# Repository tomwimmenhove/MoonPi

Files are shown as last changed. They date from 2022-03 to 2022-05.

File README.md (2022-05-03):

A simple Linux-board with a mini PCIe slot for a 4G LTE module and a 100MBit ethernet port to use as a 4G router.

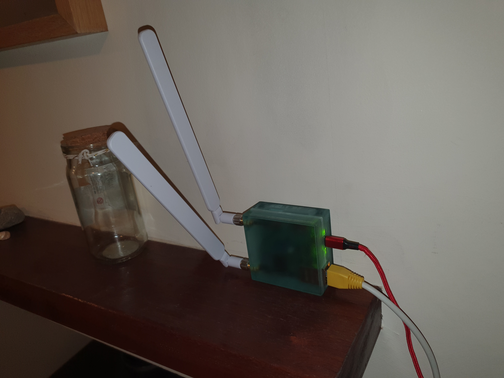
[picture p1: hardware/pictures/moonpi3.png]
MoonPi Cased


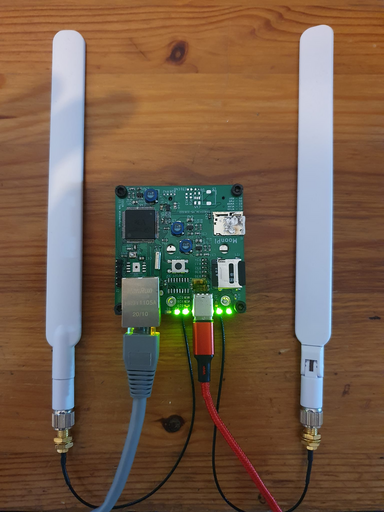
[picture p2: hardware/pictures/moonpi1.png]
MoonPi PCB front

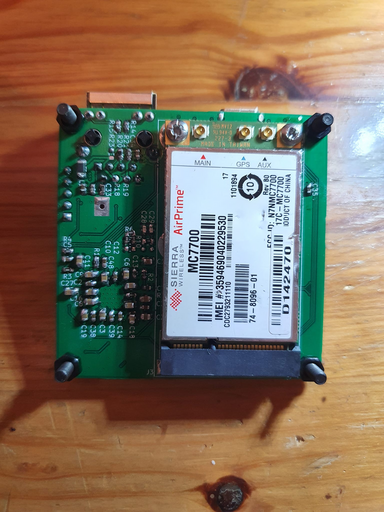
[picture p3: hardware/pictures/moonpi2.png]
MoonPi PCB bottom


Specs:
- 100MBit ethernet
- 64MB RAM
- Mini PCIe slot (for an LTE module)
- SD card slot (for firmware)
- SIM card slot
- Allwinner V3S CPU
- 115k2 baud UART console/debugging interface (Optionally over USB)

Thanks to [Dmitry Poskriyakov](https://github.com/balmerdx/AllwinnerV3S_KiCad) for creating the footprints for the used Allwinner V3S CPU.

Multiple kernel versions with working .config files can be found [here](https://github.com/tomwimmenhove/moonpi-linux/).
A U-boot .config is included in [this repository](https://github.com/tomwimmenhove/AllwinnerLTE/blob/main/software/config_notes/uboot.config) and a working version of U-Boot has been forked [here](https://github.com/tomwimmenhove/u-boot).
And finally, ~a working filesystem for the SD-card can be found [here](https://drive.google.com/drive/folders/1GH_1jrhb02dNxiufkJj9f3y94fUZBKtc)~ a working SD-card image with OpenWRT is available [here](https://github.com/tomwimmenhove/MoonPi/blob/main/software/sd_card_image/openwrt.img.gz?raw=true).

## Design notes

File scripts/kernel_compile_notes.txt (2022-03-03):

cd linux
make ARCH=arm licheepi_zero_defconfig
make ARCH=arm menuconfig #add bluethooth, etc.
make ARCH=arm CROSS_COMPILE=arm-linux-gnueabihf- -j16
make ARCH=arm CROSS_COMPILE=arm-linux-gnueabihf- -j16 INSTALL_MOD_PATH=out modules
make ARCH=arm CROSS_COMPILE=arm-linux-gnueabihf- -j16 INSTALL_MOD_PATH=out modules_install

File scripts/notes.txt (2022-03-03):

https://techship.com/faq/how-to-step-by-step-set-up-a-data-connection-over-qmi-interface-using-qmicli-and-in-kernel-driver-qmi-wwan-in-linux/
https://electronproton.com/mmcli-command-examples/
From https://forums.quectel.com/t/quectel-eg25-connection-problem/8797/5
ifconfig wwan0 down
echo Y > /sys/class/net/wwan0/qmi/raw_ip
ifconfig wwan0 up
qmicli -d /dev/cdc-wdm0 --dms-set-operating-mode=online
qmicli -p -d /dev/cdc-wdm0 --device-open-net=‘net-raw-ip|net-no-qos-header’ --wds-start-network=“autoconnect=no,apn=‘airteliot.com’,ip-type=4” --client-no-release-cid
udhcpc -i wwan0

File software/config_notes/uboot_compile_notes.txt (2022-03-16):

Repository: https://github.com/tomwimmenhove/u-boot

Branch: v3s-current
.config: uboot.config

make ARCH=arm CROSS_COMPILE=arm-linux-gnueabihf- LicheePi_Zero_defconfig
make ARCH=arm menuconfig
make ARCH=arm CROSS_COMPILE=arm-linux-gnueabihf- -j8

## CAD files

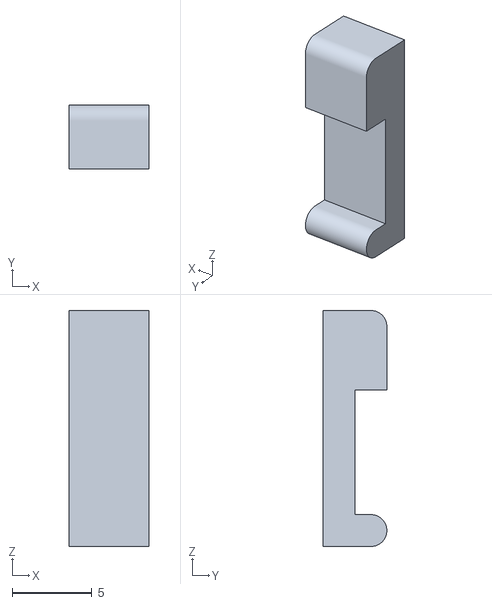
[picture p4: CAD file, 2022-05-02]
mechanical/clip.stl
5.00 x 4.00 x 14.8

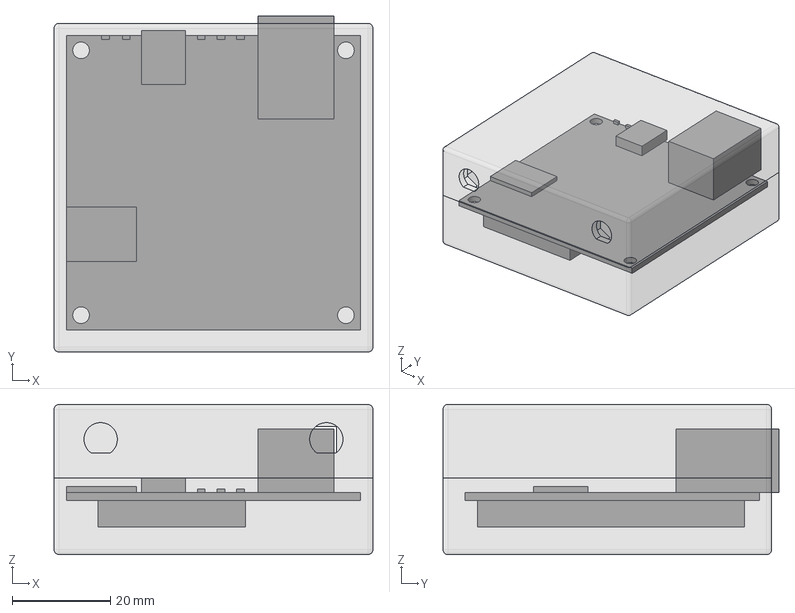
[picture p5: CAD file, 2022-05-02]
mechanical/housing.FCStd
65.0 x 68.5 x 30.6 mm
Board

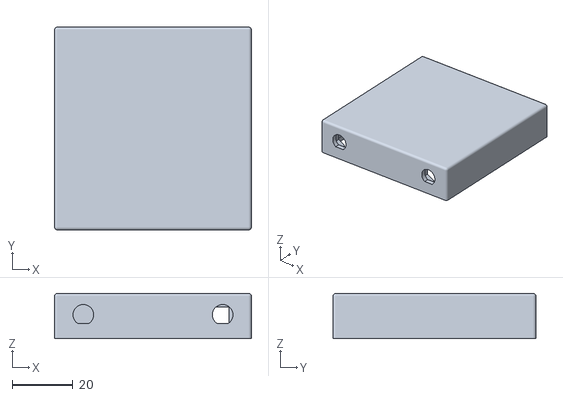
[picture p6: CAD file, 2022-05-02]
mechanical/newnewnewtop.stl
65.0 x 67.0 x 15.0

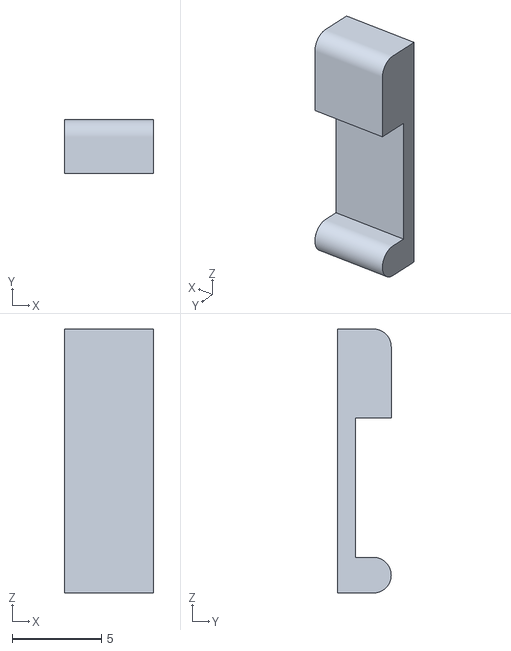
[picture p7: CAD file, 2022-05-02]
mechanical/thinclip.stl
5.00 x 3.00 x 14.8

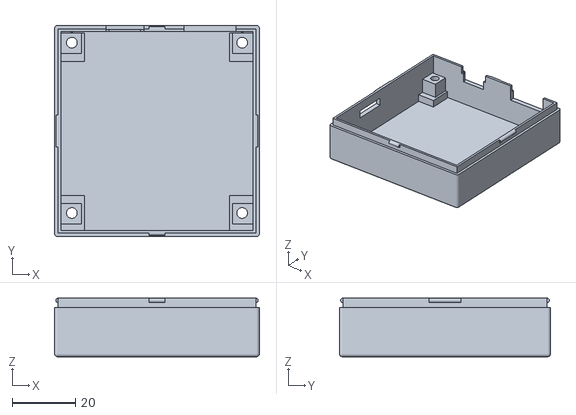
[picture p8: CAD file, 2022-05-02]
mechanical/newnewnewbottom.stl
65.0 x 67.0 x 18.6

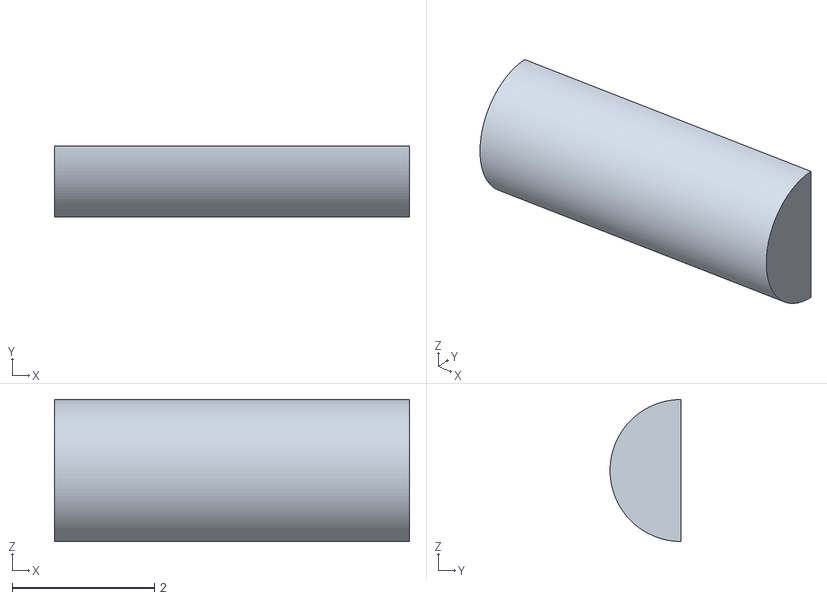
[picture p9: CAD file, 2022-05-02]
mechanical/latch.stl
5.00 x 1.00 x 2.00

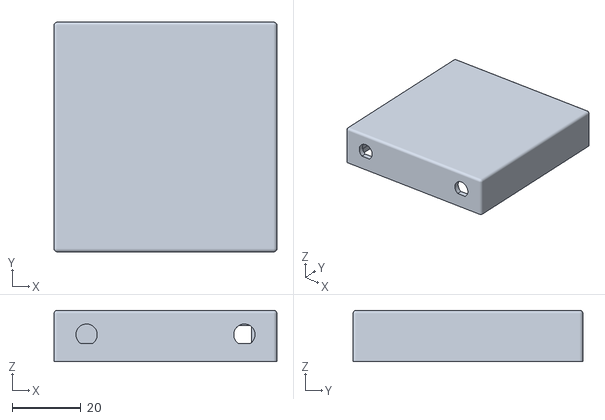
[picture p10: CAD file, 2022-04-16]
mechanical/top.stl
65.0 x 67.0 x 15.0

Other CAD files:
mechanical/newnewtop.stl
mechanical/newtop.stl
mechanical/newnewbottom.stl
mechanical/newbottom.stl
mechanical/bottom.stl

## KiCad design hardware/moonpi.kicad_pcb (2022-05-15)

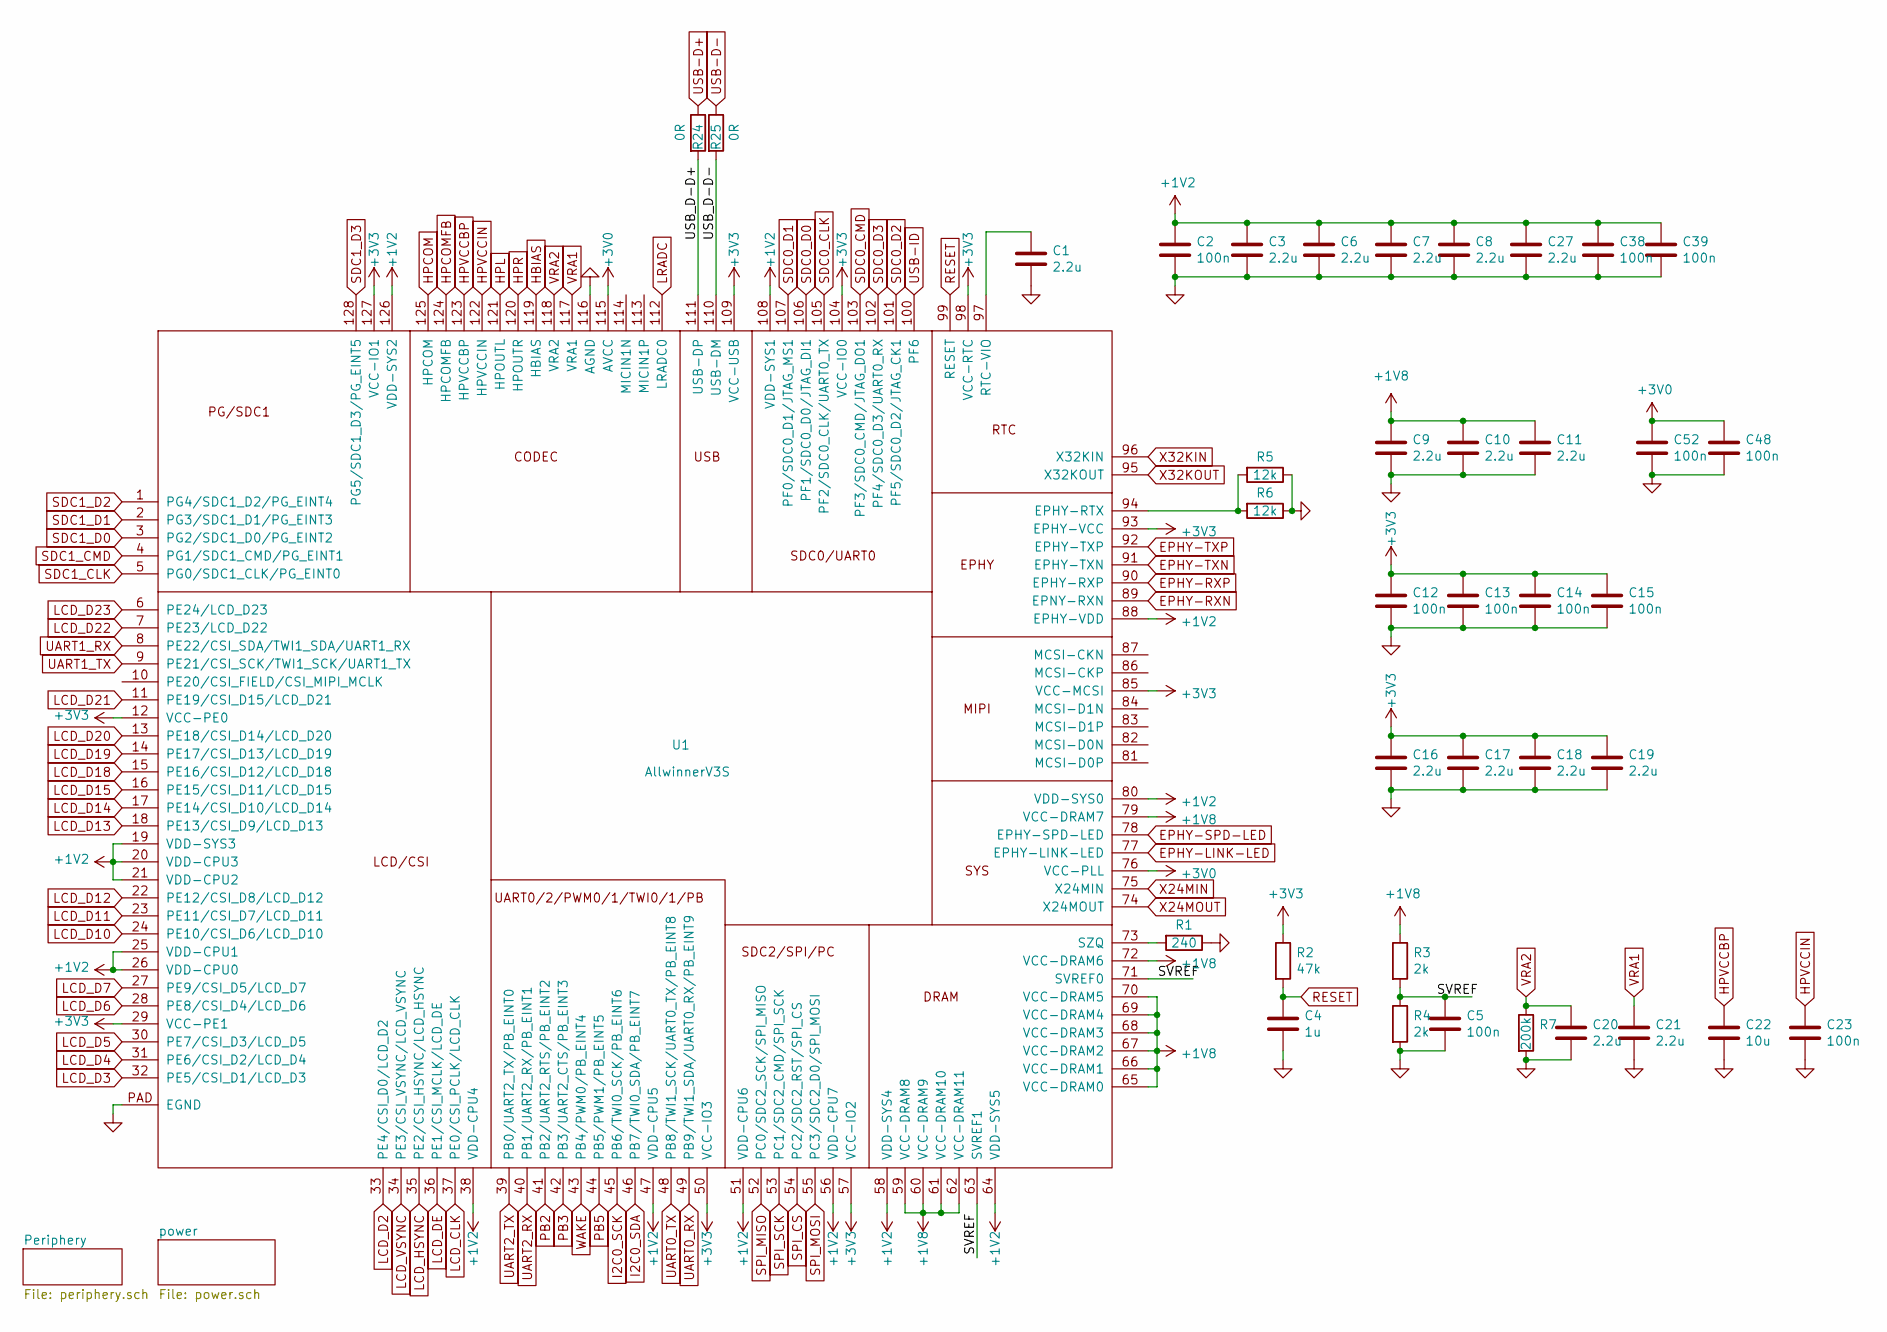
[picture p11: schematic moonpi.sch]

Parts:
C1, C3, C6, C7, C8, C9, C10, C11, C16, C17, C18, C19, C20, C21, C27: 2.2u; C_0805_2012Metric
C2, C5, C12, C13, C14, C15, C23, C38, C39, C48, C52: 100n; C_0603_1608Metric
C4: 1u; C_0603_1608Metric
C22: 10u; C_0805_2012Metric
R1: 240; R_0603_1608Metric
R2: 47k; R_0603_1608Metric
R3, R4: 2k; R_0603_1608Metric
R5, R6: 12k; R_0603_1608Metric
R7: 200k; R_0603_1608Metric
R24, R25: 0R; R_0603_1608Metric
U1: AllwinnerV3S; eLQFP-128_14x14mm_P0.4mm

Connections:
+1V2: C2.1, C3.1, C6.1, C7.1, C8.1, C27.1, C38.1, C39.1, U1.19 (VDD-SYS3), U1.20 (VDD-CPU3), U1.21 (VDD-CPU2), U1.25 (VDD-CPU1), U1.26 (VDD-CPU0), U1.38 (VDD-CPU4), U1.47 (VDD-CPU5), U1.51 (VDD-CPU6), U1.56 (VDD-CPU7), U1.58 (VDD-SYS4), U1.64 (VDD-SYS5), U1.80 (VDD-SYS0), U1.88 (EPHY-VDD), U1.108 (VDD-SYS1), U1.126 (VDD-SYS2); also elsewhere on the board
+1V8: C9.1, C10.1, C11.1, R3.1, U1.59 (VCC-DRAM8), U1.60 (VCC-DRAM9), U1.61 (VCC-DRAM10), U1.62 (VCC-DRAM11), U1.65 (VCC-DRAM0), U1.66 (VCC-DRAM1), U1.67 (VCC-DRAM2), U1.68 (VCC-DRAM3), U1.69 (VCC-DRAM4), U1.70 (VCC-DRAM5), U1.72 (VCC-DRAM6), U1.79 (VCC-DRAM7); also elsewhere on the board
+3V0: C48.1, C52.1, U1.76 (VCC-PLL), U1.115 (AVCC); also elsewhere on the board
+3V3: C12.1, C13.1, C14.1, C15.1, C16.1, C17.1, C18.1, C19.1, R2.1, U1.12 (VCC-PE0), U1.29 (VCC-PE1), U1.50 (VCC-IO3), U1.57 (VCC-IO2), U1.85 (VCC-MCSI), U1.93 (EPHY-VCC), U1.98 (VCC-RTC), U1.104 (VCC-IO0), U1.109 (VCC-USB), U1.127 (VCC-IO1); also elsewhere on the board
/SVREF: C5.1, R3.2, R4.1, U1.63 (SVREF1), U1.71 (SVREF0)
/USB_D-D+: R24.2, U1.111 (USB-DP)
/USB_D-D-: R25.2, U1.110 (USB-DM)
EPHY-LINK-LED: U1.77 (EPHY-LINK-LED); also elsewhere on the board
EPHY-RXN: U1.89 (EPNY-RXN); also elsewhere on the board
EPHY-RXP: U1.90 (EPHY-RXP); also elsewhere on the board
EPHY-SPD-LED: U1.78 (EPHY-SPD-LED); also elsewhere on the board
EPHY-TXN: U1.91 (EPHY-TXN); also elsewhere on the board
EPHY-TXP: U1.92 (EPHY-TXP); also elsewhere on the board
GND: C1.2, C2.2, C3.2, C4.2, C5.2, C6.2, C7.2, C8.2, C9.2, C10.2, C11.2, C12.2, C13.2, C14.2, C15.2, C16.2, C17.2, C18.2, C19.2, C20.2, C21.2, C22.2, C23.2, C27.2, C38.2, C39.2, C48.2, C52.2, R1.1, R4.2, R5.1, R6.1, R7.2, U1.116 (AGND), U1.PAD (EGND); also elsewhere on the board
HBIAS: U1.119 (HBIAS)
HPCOM: U1.125 (HPCOM)
HPCOMFB: U1.124 (HPCOMFB)
HPL: U1.121 (HPOUTL)
HPR: U1.120 (HPOUTR)
HPVCCBP: C22.1, U1.123 (HPVCCBP)
HPVCCIN: C23.1, U1.122 (HPVCCIN)
I2C0_SCK: U1.45 (PB6/TWI0_SCK/PB_EINT6)
I2C0_SDA: U1.46 (PB7/TWI0_SDA/PB_EINT7)
LCD_CLK: U1.37 (PE0/CSI_PCLK/LCD_CLK)
LCD_D2: U1.33 (PE4/CSI_D0/LCD_D2)
LCD_D3: U1.32 (PE5/CSI_D1/LCD_D3)
LCD_D4: U1.31 (PE6/CSI_D2/LCD_D4)
LCD_D5: U1.30 (PE7/CSI_D3/LCD_D5)
LCD_D6: U1.28 (PE8/CSI_D4/LCD_D6)
LCD_D7: U1.27 (PE9/CSI_D5/LCD_D7)
LCD_D10: U1.24 (PE10/CSI_D6/LCD_D10)
LCD_D11: U1.23 (PE11/CSI_D7/LCD_D11)
LCD_D12: U1.22 (PE12/CSI_D8/LCD_D12)
LCD_D13: U1.18 (PE13/CSI_D9/LCD_D13)
LCD_D14: U1.17 (PE14/CSI_D10/LCD_D14)
LCD_D15: U1.16 (PE15/CSI_D11/LCD_D15)
LCD_D18: U1.15 (PE16/CSI_D12/LCD_D18)
LCD_D19: U1.14 (PE17/CSI_D13/LCD_D19)
LCD_D20: U1.13 (PE18/CSI_D14/LCD_D20)
LCD_D21: U1.11 (PE19/CSI_D15/LCD_D21)
LCD_D22: U1.7 (PE23/LCD_D22)
LCD_D23: U1.6 (PE24/LCD_D23)
LCD_DE: U1.36 (PE1/CSI_MCLK/LCD_DE)
LCD_HSYNC: U1.35 (PE2/CSI_HSYNC/LCD_HSYNC)
LCD_VSYNC: U1.34 (PE3/CSI_VSYNC/LCD_VSYNC)
LRADC: U1.112 (LRADC0)
unnamed: C1.1, U1.97 (RTC-VIO)
unnamed: R1.2, U1.73 (SZQ)
unnamed: R5.2, R6.2, U1.94 (EPHY-RTX)
PB2: U1.41 (PB2/UART2_RTS/PB_EINT2)
PB3: U1.42 (PB3/UART2_CTS/PB_EINT3)
PB5: U1.44 (PB5/PWM1/PB_EINT5)
RESET: C4.1, R2.2, U1.99 (RESET); also elsewhere on the board
SDC0_CLK: U1.105 (PF2/SDC0_CLK/UART0_TX); also elsewhere on the board
SDC0_CMD: U1.103 (PF3/SDC0_CMD/JTAG_DO1); also elsewhere on the board
SDC0_D0: U1.106 (PF1/SDC0_D0/JTAG_DI1); also elsewhere on the board
SDC0_D1: U1.107 (PF0/SDC0_D1/JTAG_MS1); also elsewhere on the board
SDC0_D2: U1.101 (PF5/SDC0_D2/JTAG_CK1); also elsewhere on the board
SDC0_D3: U1.102 (PF4/SDC0_D3/UART0_RX); also elsewhere on the board
SDC1_CLK: U1.5 (PG0/SDC1_CLK/PG_EINT0); also elsewhere on the board
SDC1_CMD: U1.4 (PG1/SDC1_CMD/PG_EINT1)
SDC1_D0: U1.3 (PG2/SDC1_D0/PG_EINT2)
SDC1_D1: U1.2 (PG3/SDC1_D1/PG_EINT3)
SDC1_D2: U1.1 (PG4/SDC1_D2/PG_EINT4)
SDC1_D3: U1.128 (PG5/SDC1_D3/PG_EINT5)
SPI_CS: U1.54 (PC2/SDC2_RST/SPI_CS); also elsewhere on the board
SPI_MISO: U1.52 (PC0/SDC2_SCK/SPI_MISO); also elsewhere on the board
SPI_MOSI: U1.55 (PC3/SDC2_D0/SPI_MOSI); also elsewhere on the board
SPI_SCK: U1.53 (PC1/SDC2_CMD/SPI_SCK); also elsewhere on the board
UART0_RX: U1.49 (PB9/TWI1_SDA/UART0_RX/PB_EINT9); also elsewhere on the board
UART0_TX: U1.48 (PB8/TWI1_SCK/UART0_TX/PB_EINT8); also elsewhere on the board
UART1_RX: U1.8 (PE22/CSI_SDA/TWI1_SDA/UART1_RX)
UART1_TX: U1.9 (PE21/CSI_SCK/TWI1_SCK/UART1_TX)
UART2_RX: U1.40 (PB1/UART2_RX/PB_EINT1)
UART2_TX: U1.39 (PB0/UART2_TX/PB_EINT0)
USB-D+: R24.1; also elsewhere on the board
USB-D-: R25.1; also elsewhere on the board
USB-ID: U1.100 (PF6); also elsewhere on the board
VRA1: C21.1, U1.117 (VRA1)
VRA2: C20.1, R7.1, U1.118 (VRA2)
WAKE: U1.43 (PB4/PWM0/PB_EINT4); also elsewhere on the board
X24MIN: U1.75 (X24MIN); also elsewhere on the board
X24MOUT: U1.74 (X24MOUT); also elsewhere on the board
X32KIN: U1.96 (X32KIN); also elsewhere on the board
X32KOUT: U1.95 (X32KOUT); also elsewhere on the board

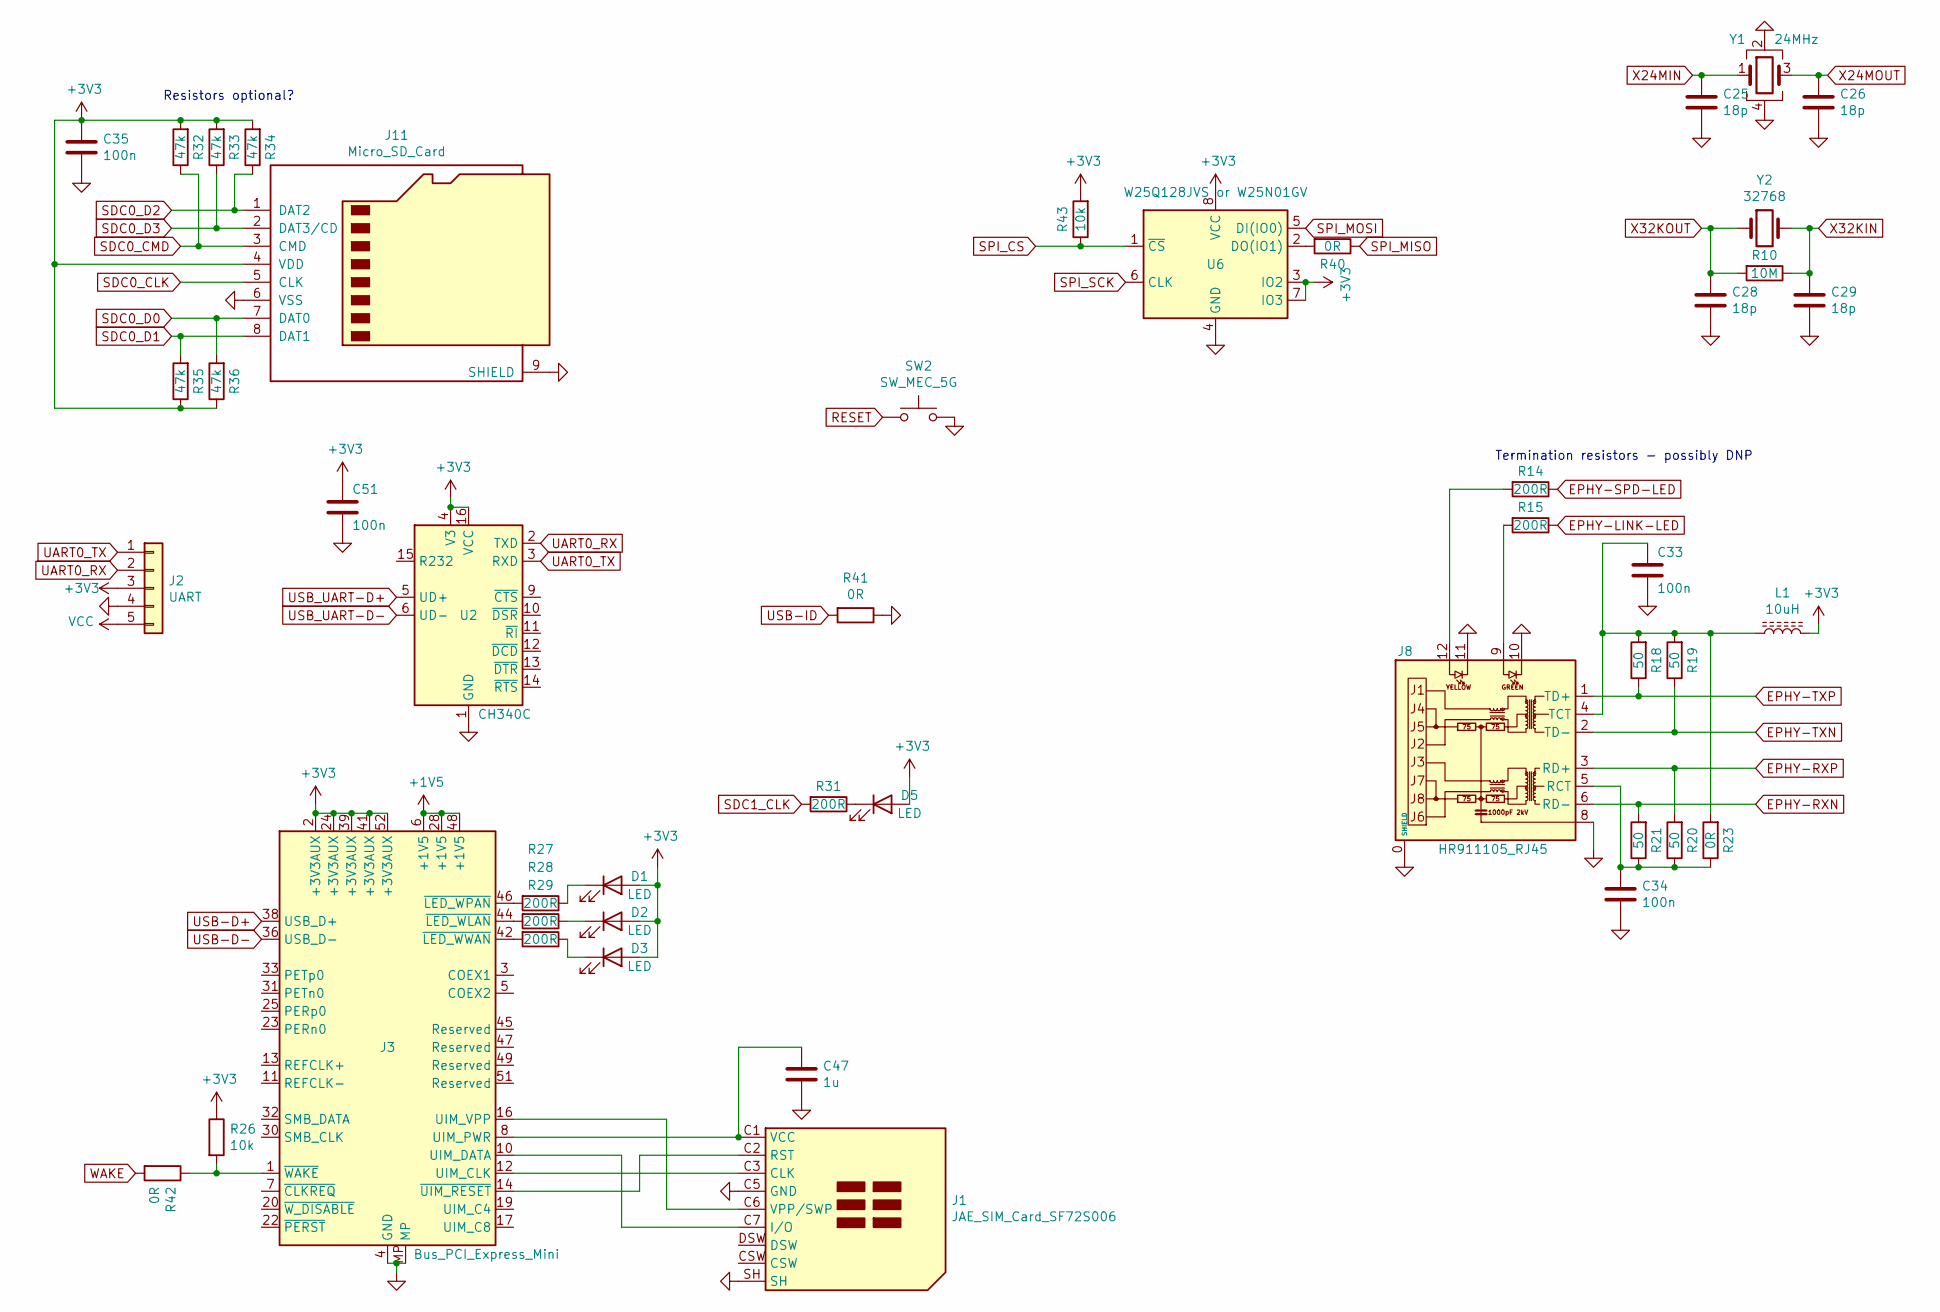
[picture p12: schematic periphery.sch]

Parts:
C25, C26, C28, C29: 18p; C_0603_1608Metric
C33, C34, C35, C51: 100n; C_0603_1608Metric
C47: 1u; C_0603_1608Metric
D1, D2, D3, D5: LED; LED_0603_1608Metric
J1: JAE_SIM_Card_SF72S006
J2: UART; PinHeader_1x05_P2.54mm_Vertical
J3: Bus_PCI_Express_Mini; BUS_PCI_Express_Mini_Dual
J8: HR911105_RJ45
J11: Micro_SD_Card; microSD_HC_Wuerth_693072010801
L1: 10uH; L_1206_3216Metric
R10: 10M; R_0805_2012Metric
R14, R15, R27, R28, R29, R31: 200R; R_0603_1608Metric
R18, R19, R20, R21: 50; R_0603_1608Metric
R23, R40, R41, R42: 0R; R_0603_1608Metric
R26, R43: 10k; R_0603_1608Metric
R32, R33, R34, R35, R36: 47k; R_0603_1608Metric
SW2: SW_MEC_5G; SW_SPST_Omron_B3FS-100xP
U2: CH340C; SOIC-16_3.9x9.9mm_P1.27mm
U6: W25Q128JVS or W25N01GV; SOIC-8_5.23x5.23mm_P1.27mm
Y1: 24MHz; Crystal_SMD_3225-4Pin_3.2x2.5mm
Y2: 32768; Crystal_C26-LF_D2.1mm_L6.5mm_Horizontal

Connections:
+1V5: J3.6 (+1V5), J3.28 (+1V5), J3.48 (+1V5); also elsewhere on the board
+3V3: C35.1, C51.1, D1.2 (A), D2.2 (A), D3.2 (A), D5.2 (A), J2.3, J3.2 (+3V3AUX), J3.24 (+3V3AUX), J3.39 (+3V3AUX), J3.41 (+3V3AUX), J3.52 (+3V3AUX), J11.4 (VDD), L1.2, R26.1, R32.2, R33.2, R34.2, R35.1, R36.1, R43.2, U2.4 (V3), U2.16 (VCC), U6.3 (IO2), U6.7 (IO3), U6.8 (VCC); also elsewhere on the board
EPHY-LINK-LED: R15.1; also elsewhere on the board
EPHY-RXN: J8.6 (RD-), R21.2; also elsewhere on the board
EPHY-RXP: J8.3 (RD+), R20.2; also elsewhere on the board
EPHY-SPD-LED: R14.1; also elsewhere on the board
EPHY-TXN: J8.2 (TD-), R19.1; also elsewhere on the board
EPHY-TXP: J8.1 (TD+), R18.1; also elsewhere on the board
GND: C25.2, C26.2, C28.2, C29.2, C33.2, C34.2, C35.2, C47.2, C51.2, J1.C5 (GND), J1.SH, J2.4, J3.4 (GND), J3.9 (GND), J3.15 (GND), J3.18 (GND), J3.21 (GND), J3.26 (GND), J3.27 (GND), J3.29 (GND), J3.34 (GND), J3.35 (GND), J3.37 (GND), J3.40 (GND), J3.43 (GND), J3.50 (GND), J3.MP, J8.0 (SHIELD), J8.8, J8.10, J8.11, J11.6 (VSS), J11.9 (SHIELD), R41.1, SW2.3 (B), SW2.4 (B), U2.1 (GND), U6.4 (GND), Y1.2, Y1.4; also elsewhere on the board
unnamed: C33.1, J8.4 (TCT), L1.1, R18.2, R19.2, R23.2
unnamed: C34.1, J8.5 (RCT), R20.1, R21.1, R23.1
unnamed: C47.1, J1.C1 (VCC), J3.8 (UIM_PWR)
unnamed: D1.1 (K), R27.1
unnamed: D2.1 (K), R28.1
unnamed: D3.1 (K), R29.1
unnamed: D5.1 (K), R31.1
unnamed: J1.C2 (RST), J3.14 (~UIM_RESET)
unnamed: J1.C3 (CLK), J3.12 (UIM_CLK)
unnamed: J1.C6 (VPP/SWP), J3.16 (UIM_VPP)
unnamed: J1.C7 (I/O), J3.10 (UIM_DATA)
unnamed: J3.1 (~WAKE), R26.2, R42.1
unnamed: J3.42 (~LED_WWAN), R29.2
unnamed: J3.44 (~LED_WLAN), R28.2
unnamed: J3.46 (~LED_WPAN), R27.2
unnamed: J8.9, R15.2
unnamed: J8.12, R14.2
unnamed: R40.2, U6.2 (DO(IO1))
RESET: SW2.1 (A), SW2.2 (A); also elsewhere on the board
SDC0_CLK: J11.5 (CLK); also elsewhere on the board
SDC0_CMD: J11.3 (CMD), R32.1; also elsewhere on the board
SDC0_D0: J11.7 (DAT0), R36.2; also elsewhere on the board
SDC0_D1: J11.8 (DAT1), R35.2; also elsewhere on the board
SDC0_D2: J11.1 (DAT2), R34.1; also elsewhere on the board
SDC0_D3: J11.2 (DAT3/CD), R33.1; also elsewhere on the board
SDC1_CLK: R31.2; also elsewhere on the board
SPI_CS: R43.1, U6.1 (~CS); also elsewhere on the board
SPI_MISO: R40.1; also elsewhere on the board
SPI_MOSI: U6.5 (DI(IO0)); also elsewhere on the board
SPI_SCK: U6.6 (CLK); also elsewhere on the board
UART0_RX: J2.2, U2.2 (TXD); also elsewhere on the board
UART0_TX: J2.1, U2.3 (RXD); also elsewhere on the board
USB-D+: J3.38 (USB_D+); also elsewhere on the board
USB-D-: J3.36 (USB_D-); also elsewhere on the board
USB-ID: R41.2; also elsewhere on the board
USB_UART-D+: U2.5 (UD+); also elsewhere on the board
USB_UART-D-: U2.6 (UD-); also elsewhere on the board
VCC: J2.5; also elsewhere on the board
WAKE: R42.2; also elsewhere on the board
X24MIN: C25.1, Y1.1; also elsewhere on the board
X24MOUT: C26.1, Y1.3; also elsewhere on the board
X32KIN: C29.1, R10.1, Y2.2; also elsewhere on the board
X32KOUT: C28.1, R10.2, Y2.1; also elsewhere on the board

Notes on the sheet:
Termination resistors - possibly DNP
Resistors optional?

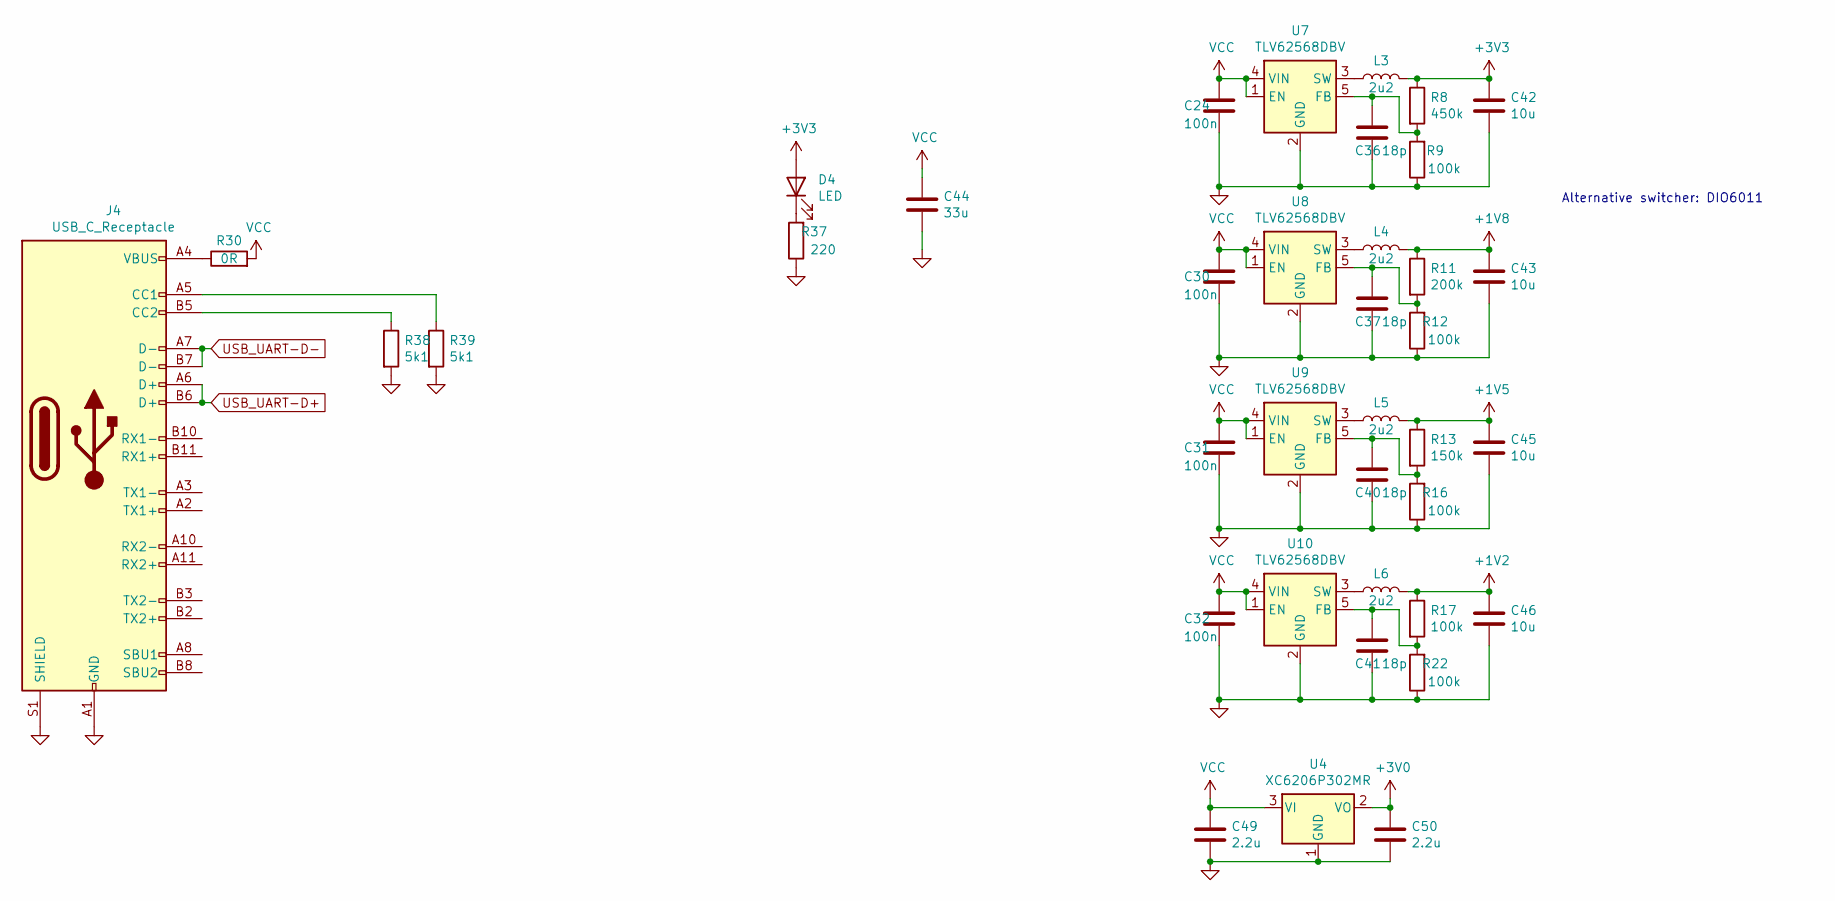
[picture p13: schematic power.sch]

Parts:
C24, C30, C31, C32: 100n; C_0603_1608Metric
C36, C37, C40, C41: 18p; C_0603_1608Metric
C42, C43, C45, C46: 10u; C_0805_2012Metric
C44: 33u; C_1206_3216Metric
C49, C50: 2.2u; C_0805_2012Metric
D4: LED; LED_0603_1608Metric
J4: USB_C_Receptacle; USB_C_Receptacle_Amphenol_12401610E4-2A
L3, L4, L5, L6: 2u2; L_TDK_SLF6045
R8: 450k; R_0603_1608Metric
R9, R12, R16, R17, R22: 100k; R_0603_1608Metric
R11: 200k; R_0603_1608Metric
R13: 150k; R_0603_1608Metric
R30: 0R; R_0603_1608Metric
R37: 220; R_0603_1608Metric
R38, R39: 5k1; R_0603_1608Metric
U4: XC6206P302MR; SOT-23
U7, U8, U9, U10: TLV62568DBV; SOT-23-5

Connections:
+1V2: C46.1, L6.2, R17.1; also elsewhere on the board
+1V5: C45.1, L5.2, R13.1; also elsewhere on the board
+1V8: C43.1, L4.2, R11.1; also elsewhere on the board
+3V0: C50.1, U4.2 (VO); also elsewhere on the board
+3V3: C42.1, D4.2 (A), L3.2, R8.1; also elsewhere on the board
GND: C24.2, C30.2, C31.2, C32.2, C36.2, C37.2, C40.2, C41.2, C42.2, C43.2, C44.2, C45.2, C46.2, C49.2, C50.2, J4.A1 (GND), J4.A12 (GND), J4.B1 (GND), J4.B12 (GND), J4.S1 (SHIELD), R9.1, R12.1, R16.1, R22.1, R37.1, R38.2, R39.2, U4.1 (GND), U7.2 (GND), U8.2 (GND), U9.2 (GND), U10.2 (GND); also elsewhere on the board
unnamed: C36.1, R8.2, R9.2, U7.5 (FB)
unnamed: C37.1, R11.2, R12.2, U8.5 (FB)
unnamed: C40.1, R13.2, R16.2, U9.5 (FB)
unnamed: C41.1, R17.2, R22.2, U10.5 (FB)
unnamed: D4.1 (K), R37.2
unnamed: J4.A4 (VBUS), J4.A9 (VBUS), J4.B4 (VBUS), J4.B9 (VBUS), R30.1
unnamed: J4.A5 (CC1), R39.1
unnamed: J4.B5 (CC2), R38.1
unnamed: L3.1, U7.3 (SW)
unnamed: L4.1, U8.3 (SW)
unnamed: L5.1, U9.3 (SW)
unnamed: L6.1, U10.3 (SW)
USB_UART-D+: J4.A6 (D+), J4.B6 (D+); also elsewhere on the board
USB_UART-D-: J4.A7 (D-), J4.B7 (D-); also elsewhere on the board
VCC: C24.1, C30.1, C31.1, C32.1, C44.1, C49.1, R30.2, U4.3 (VI), U7.1 (EN), U7.4 (VIN), U8.1 (EN), U8.4 (VIN), U9.1 (EN), U9.4 (VIN), U10.1 (EN), U10.4 (VIN); also elsewhere on the board

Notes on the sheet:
Alternative switcher: DIO6011

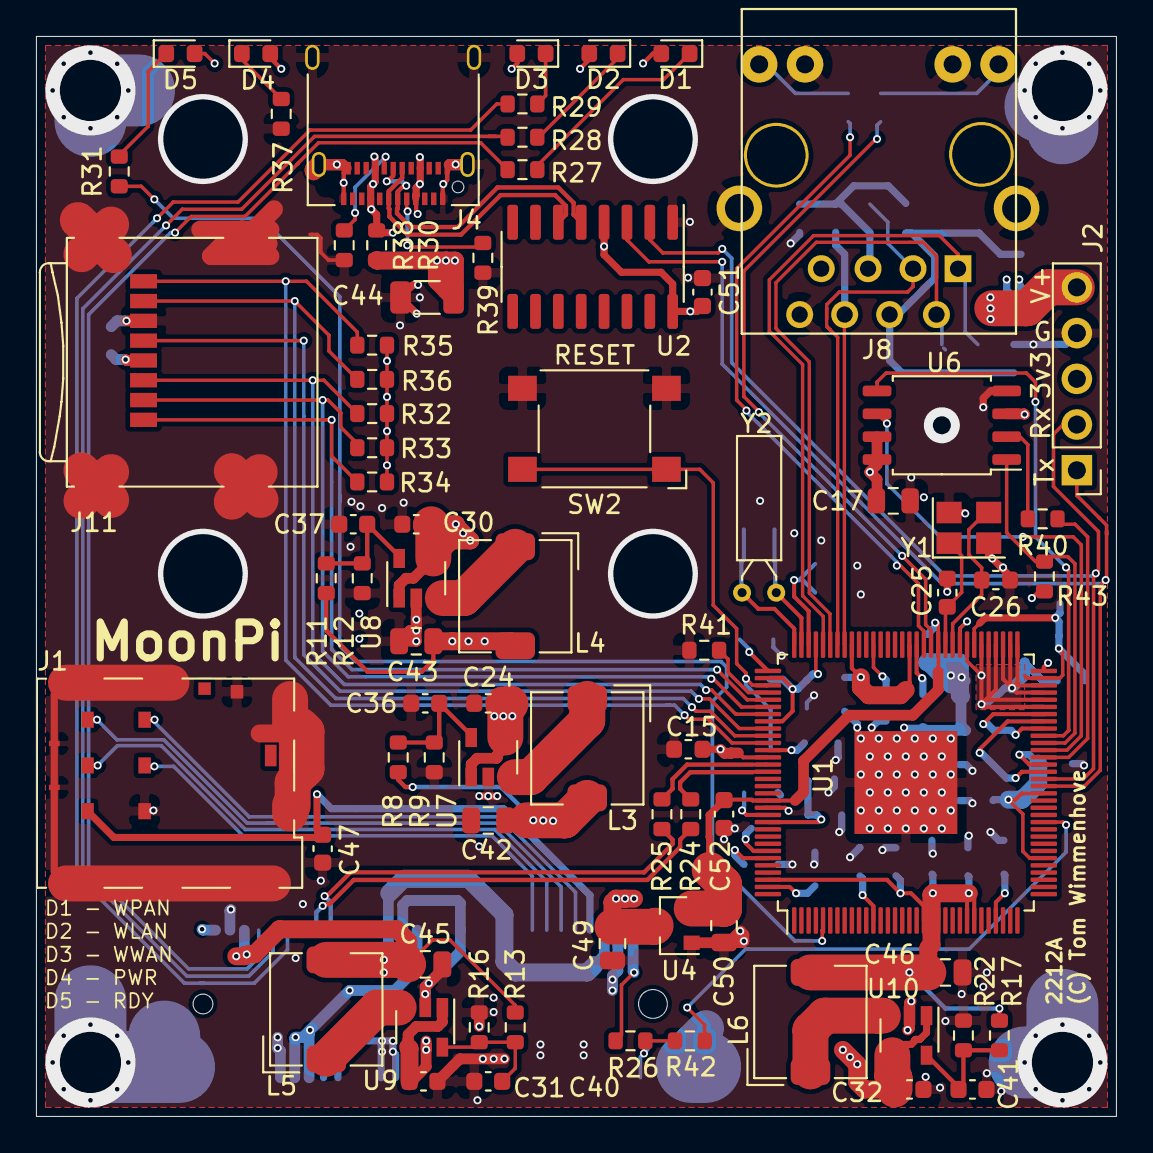
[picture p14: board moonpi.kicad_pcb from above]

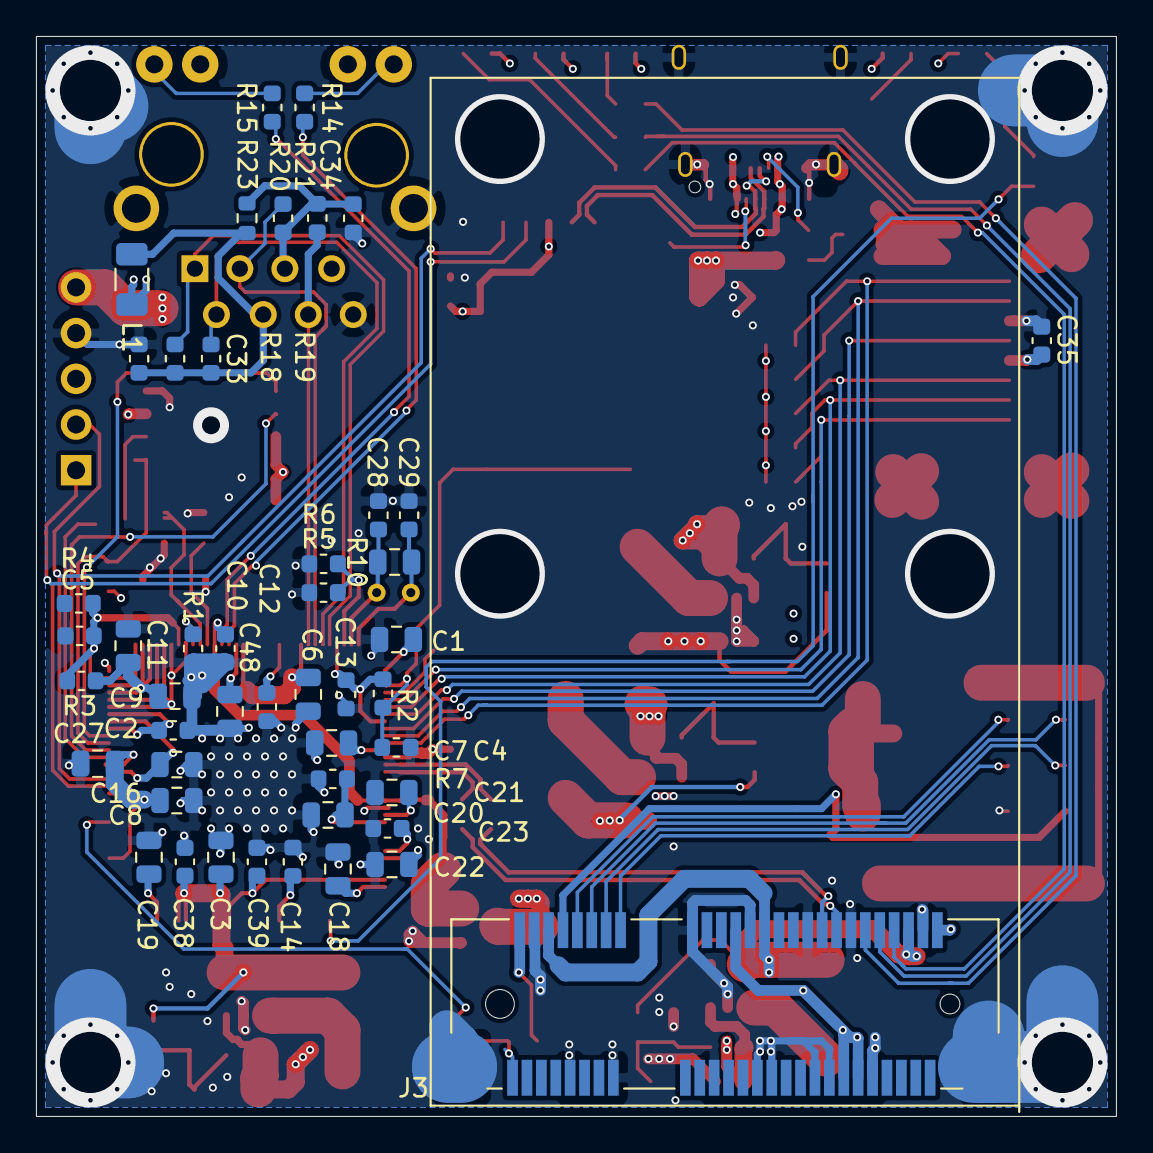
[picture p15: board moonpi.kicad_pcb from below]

Board: 4 copper layers, 60.0 x 60.0 mm, 122 parts (47 on the bottom side), 77 nets.

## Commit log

2022-02-12 Some routing done
    [balmer_allwinner_v3s_v2.kicad_pcb, balmer_allwinner_v3s_v2.sch, periphery.sch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]
2022-02-13 More routing. CPU power routed. USB li-ion charging added
    [balmer_allwinner_v3s_v2.kicad_pcb, balmer_allwinner_v3s_v2.sch, periphery.sch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]
2022-02-14 Power routing done
    [balmer_allwinner_v3s_v2.kicad_pcb, power.sch]
2022-02-15 Routing done?!
    [balmer_allwinner_v3s_v2.kicad_pcb]
2022-02-16 Fixed refdes placements
    [balmer_allwinner_v3s_v2.kicad_pcb]
2022-02-18 Small touch-ups
    [balmer_allwinner_v3s_v2.kicad_pcb, periphery.sch, power.sch]
2022-02-20 Added USB UART
    [balmer_allwinner_v3s_v2.kicad_pcb, balmer_allwinner_v3s_v2.sch, periphery.sch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]
2022-02-21 Small updates
    [balmer_allwinner_v3s_v2.kicad_pcb]
2022-02-21 Removed FEL button
    [balmer_allwinner_v3s_v2.kicad_pcb, periphery.sch]
2022-02-23 Removed USB series resistors on mPCIe side
    [balmer_allwinner_v3s_v2.kicad_pcb, periphery.sch]
2022-02-23 Fixed DRC
    [balmer_allwinner_v3s_v2.kicad_pcb]
2022-03-03 Rotated SIM
    [balmer_allwinner_v3s_v2.kicad_pcb]
2022-03-03 0R between VBus and VCC
    [balmer_allwinner_v3s_v2.kicad_pcb, power.sch]
2022-03-06 Added an "RDY" LED
    [balmer_allwinner_v3s_v2.kicad_pcb, periphery.sch, power.sch]
2022-03-06 Changed mPCIe mounting holes for PCB inserts: https://www.farnell.com/cad/2720308.pdf (length may vary
    [balmer_allwinner_v3s_v2.kicad_pcb]
2022-03-06 Removed mask and added vias around mounting pads
    [balmer_allwinner_v3s_v2.kicad_pcb]
2022-03-06 Better mechanical support on GND pads for mPCIe conn
    [balmer_allwinner_v3s_v2.kicad_pcb]
2022-03-07 Minor touch-ups
    [balmer_allwinner_v3s_v2.kicad_pcb]
2022-03-12 Added 0R for USB_ID pin + Moved OK LED to licheePi default GPIO
    [balmer_allwinner_v3s_v2.kicad_pcb, periphery.sch, power.sch]
2022-03-13 Added T-PAD below NAND Flash
    [balmer_allwinner_v3s_v2.kicad_pcb]
2022-03-13 Some routingnitpicking
    [balmer_allwinner_v3s_v2.kicad_pcb]
2022-03-13 Translated Russian comments
    [periphery.sch]
2022-03-13 Actually comitted the translation
    [power.sch]
2022-03-13 Replaced SD card slot with Wurth 693072010801
    [balmer_allwinner_v3s_v2.kicad_pcb, periphery.sch]
2022-03-13 Forgot some GND vias
    [balmer_allwinner_v3s_v2.kicad_pcb]
2022-03-14 Some routing improvements
    [balmer_allwinner_v3s_v2.kicad_pcb, periphery.sch]
2022-03-21 Move Y1 to top-layer
    [balmer_allwinner_v3s_v2.kicad_pcb, periphery.sch, power.sch]
2022-03-21 Improved spacing
    [balmer_allwinner_v3s_v2.kicad_pcb]
2022-03-21 Minor layout changes
    [balmer_allwinner_v3s_v2.kicad_pcb]
2022-03-21 Ready for JLCPCB
    [balmer_allwinner_v3s_v2.kicad_pcb]
2022-04-03 Fixed filenames
    [moonpi_v2.kicad_pcb, moonpi_v2.sch, periphery.sch]
2022-04-03 Fixed filename verioning
    [moonpi.kicad_pcb, moonpi.sch, periphery.sch]
2022-04-16 Added 3D model for case
    [bottom.stl, housing.FCStd, top.stl]
2022-04-23 Changed USB series termination resistors values to zero-ohm
    [moonpi.kicad_pcb, moonpi.sch]
2022-04-23 3D case latch and other improvements
    [housing.FCStd]
2022-04-26 Small 3D model fixes
    [housing.FCStd]
2022-04-26 Thicker USB wall
    [housing.FCStd]
2022-05-02 3D case improvements
    [clip.stl, housing.FCStd, latch.stl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]
2022-05-03 Update README.md
    Added picture of router in case.
2022-05-15 FIX: Added pull-up on SPI /CS
    [moonpi.kicad_pcb, periphery.sch]
